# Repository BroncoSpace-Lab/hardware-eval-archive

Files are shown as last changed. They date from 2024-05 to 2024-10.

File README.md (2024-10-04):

# hardware-eval-archive

This is a new repo for us to store archived hardware evaluations! 

## Archiving a New Eval
To add your recently completed eval to this repo take the following steps: 
1. Make a new branch!
2. Add your files into a new folder with your name and the date in yyyy-mm-dd format. 
3. Make a pull reqest back to the main branch!

## Hardware Eval Instructions Reference: 
Since you're interested in leaning more towards the electronics side of things, we have an evaluation that we usually give prospective hardware engineers in our lab 1 week to complete if you would like to attempt it. For that evaluation, the task will be to create a custom microcontroller development board. The requirements are as follows:

- Design a PCB that uses an [RP2040 microcontroller](https://www.raspberrypi.com/documentation/microcontrollers/rp2040.html)
- Needs to be able to boot CircuitPython.
- Board Form Factor of no greater than 50x50mm
- Has an I2C sensor integrated (any sensor).
- JLC PCB production files completed (BOM, POS, and Gerbers generated in correct format)
- Preferably designed in KiCad (Eagle or Altium will also suffice)

We understand that PCB design is not usually taught at the university level, so it is rare to have prior experience with it. This challenge is primarily to test your ability to be technically independent and learn a new design skill quickly. Both [Digikey](https://www.youtube.com/@digikey) and [Phil's Lab](https://www.youtube.com/@PhilsLab) on YouTube have excellent beginner level PCB design tutorials. If you have the time to attempt it over the weekend that would be great, but don't worry if you need more time. A follow-up design review can be scheduled to assess how you have done, and if the design looks satisfactory, we'll go ahead and order it for you to test!

__Bonus Criteria__
- Make your board as compact as possible
- Ensure that either all of the GPIO are broken out and/or have some kind of connector system (like STEMMA QT) for wiring up additional peripherals
- Make the board look cool by adding silkscreen or soldermask art!

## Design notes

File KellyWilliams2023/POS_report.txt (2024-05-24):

Info: Front (top side) placement file: 'D:\Users\2790755\Documents\KiCad\SCALES PCB\minimal viable board design files\Minimal\RP2040_minimal\RP2040_minimal-top.pos'.
Info: Component count: 35.
Info: Back (bottom side) placement file: 'D:\Users\2790755\Documents\KiCad\SCALES PCB\minimal viable board design files\Minimal\RP2040_minimal\RP2040_minimal-bottom.pos'.
Info: Component count: 0.
Info: Full component count: 35.
Info: File generation successful.

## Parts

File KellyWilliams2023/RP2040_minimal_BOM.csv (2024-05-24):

Id | Designator | Footprint | Quantity | Designation | Supplier and ref
1 | C4,C1,C17 | C_0805_2012Metric | 3 | 10u
2 | J1 | USB_Micro-B_Amphenol_10103594-0001LF_Horizontal_modified | 1 | USB_B_Micro
3 | J2 | PinHeader_1x02_P2.54mm_Vertical | 1 | Conn_01x02
4 | J3,J4 | PinHeader_2x18_P2.54mm_Vertical | 2 | Conn_02x18_Odd_Even
5 | C10,C8 | C_0402_1005Metric | 2 | 1u
6 | C13,C5,C9,C12,C14,C7,C11,C16,C6,C15,C19,C18 | C_0402_1005Metric | 12 | 100n
7 | R2 | C_0402_1005Metric | 1 | DNF
8 | U1 | SOT-223-3_TabPin2 | 1 | NCP1117-3.3_SOT223
9 | U2 | SOIC-8_5.23x5.23mm_P1.27mm | 1 | W25Q128JVS
10 | C3,C2 | C_0402_1005Metric | 2 | 27p
11 | R1,R5 | C_0402_1005Metric | 2 | 1k
12 | R3,R4 | C_0402_1005Metric | 2 | 27
13 | U3 | RP2040-QFN-56 | 1 | RP2040
14 | H2,H3,H1,H4 | MountingHole_2.7mm_M2.5 | 4 | MountingHole
15 | Y1 | Crystal_SMD_HC49-US | 1 | ABLS-12.000MHZ-B4-T
16 | R6,R7 | C_0402_1005Metric | 2 | 4.7k
17 | U4 | Bosch_LGA-8_2.5x2.5mm_P0.65mm_ClockwisePinNumbering | 1 | BME280

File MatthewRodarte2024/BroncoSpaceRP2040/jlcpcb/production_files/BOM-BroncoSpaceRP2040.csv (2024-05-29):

Comment | Designator | Footprint | LCSC
10u | C1,C16,C2 | C_0805_2012Metric | C1046
1k | R4,R5 | R_0402_1005Metric | C11702
2N3906 | Q1 | TO-92_Inline | C124483
100n | C10,C11,C12,C13,C18,C4,C5,C7,C8,C9 | C_0402_1005Metric | C1525
100p | C17 | C_0402_1005Metric | C1546
27R4 | R1,R2 | R_0402_1005Metric | C172043
15p | C14,C15 | C_0402_1005Metric | C17944
RP2040 | U1 | QFN-56-1EP_7x7mm_P0.4mm_EP3.2x3.2mm | C2040
ABM8-272-T3 | Y1 | Crystal_SMD_3225-4Pin_3.2x2.5mm | C20625731
470 | R_Limit1 | R_0603_1608Metric | C23179
10k | R10,R7,R8 | R_0402_1005Metric | C25744
NCP1117-3.3_SOT223 | U2 | SOT-223-3_TabPin2 | C26537
USB_B_Micro | J1 | USB_Micro-B_Amphenol_10103594-0001LF_Horizontal | C2681556
TMP461xxRUN | U4 | Texas_WQFN-10_2x2mm_P0.5mm | C2873234
1u | C3,C6 | C_0402_1005Metric | C52923
W25Q128JVS | U3 | SOIC-8_5.23x5.23mm_P1.27mm | C97521
MountingHole | H3 | MountingHole_2.7mm_M2.5
Conn_01x18 | J4 | PinHeader_1x18_P2.54mm_Vertical
MountingHole | H2 | MountingHole_2.7mm_M2.5
Conn_01x02 | J2 | PinHeader_1x02_P2.54mm_Vertical
MountingHole | H1 | MountingHole_2.7mm_M2.5
MountingHole | H4 | MountingHole_2.7mm_M2.5
Conn_01x18 | J3 | PinHeader_1x18_P2.54mm_Vertical
LED | D1 | LED_D3.0mm
DNF | R3 | R_0402_1005Metric

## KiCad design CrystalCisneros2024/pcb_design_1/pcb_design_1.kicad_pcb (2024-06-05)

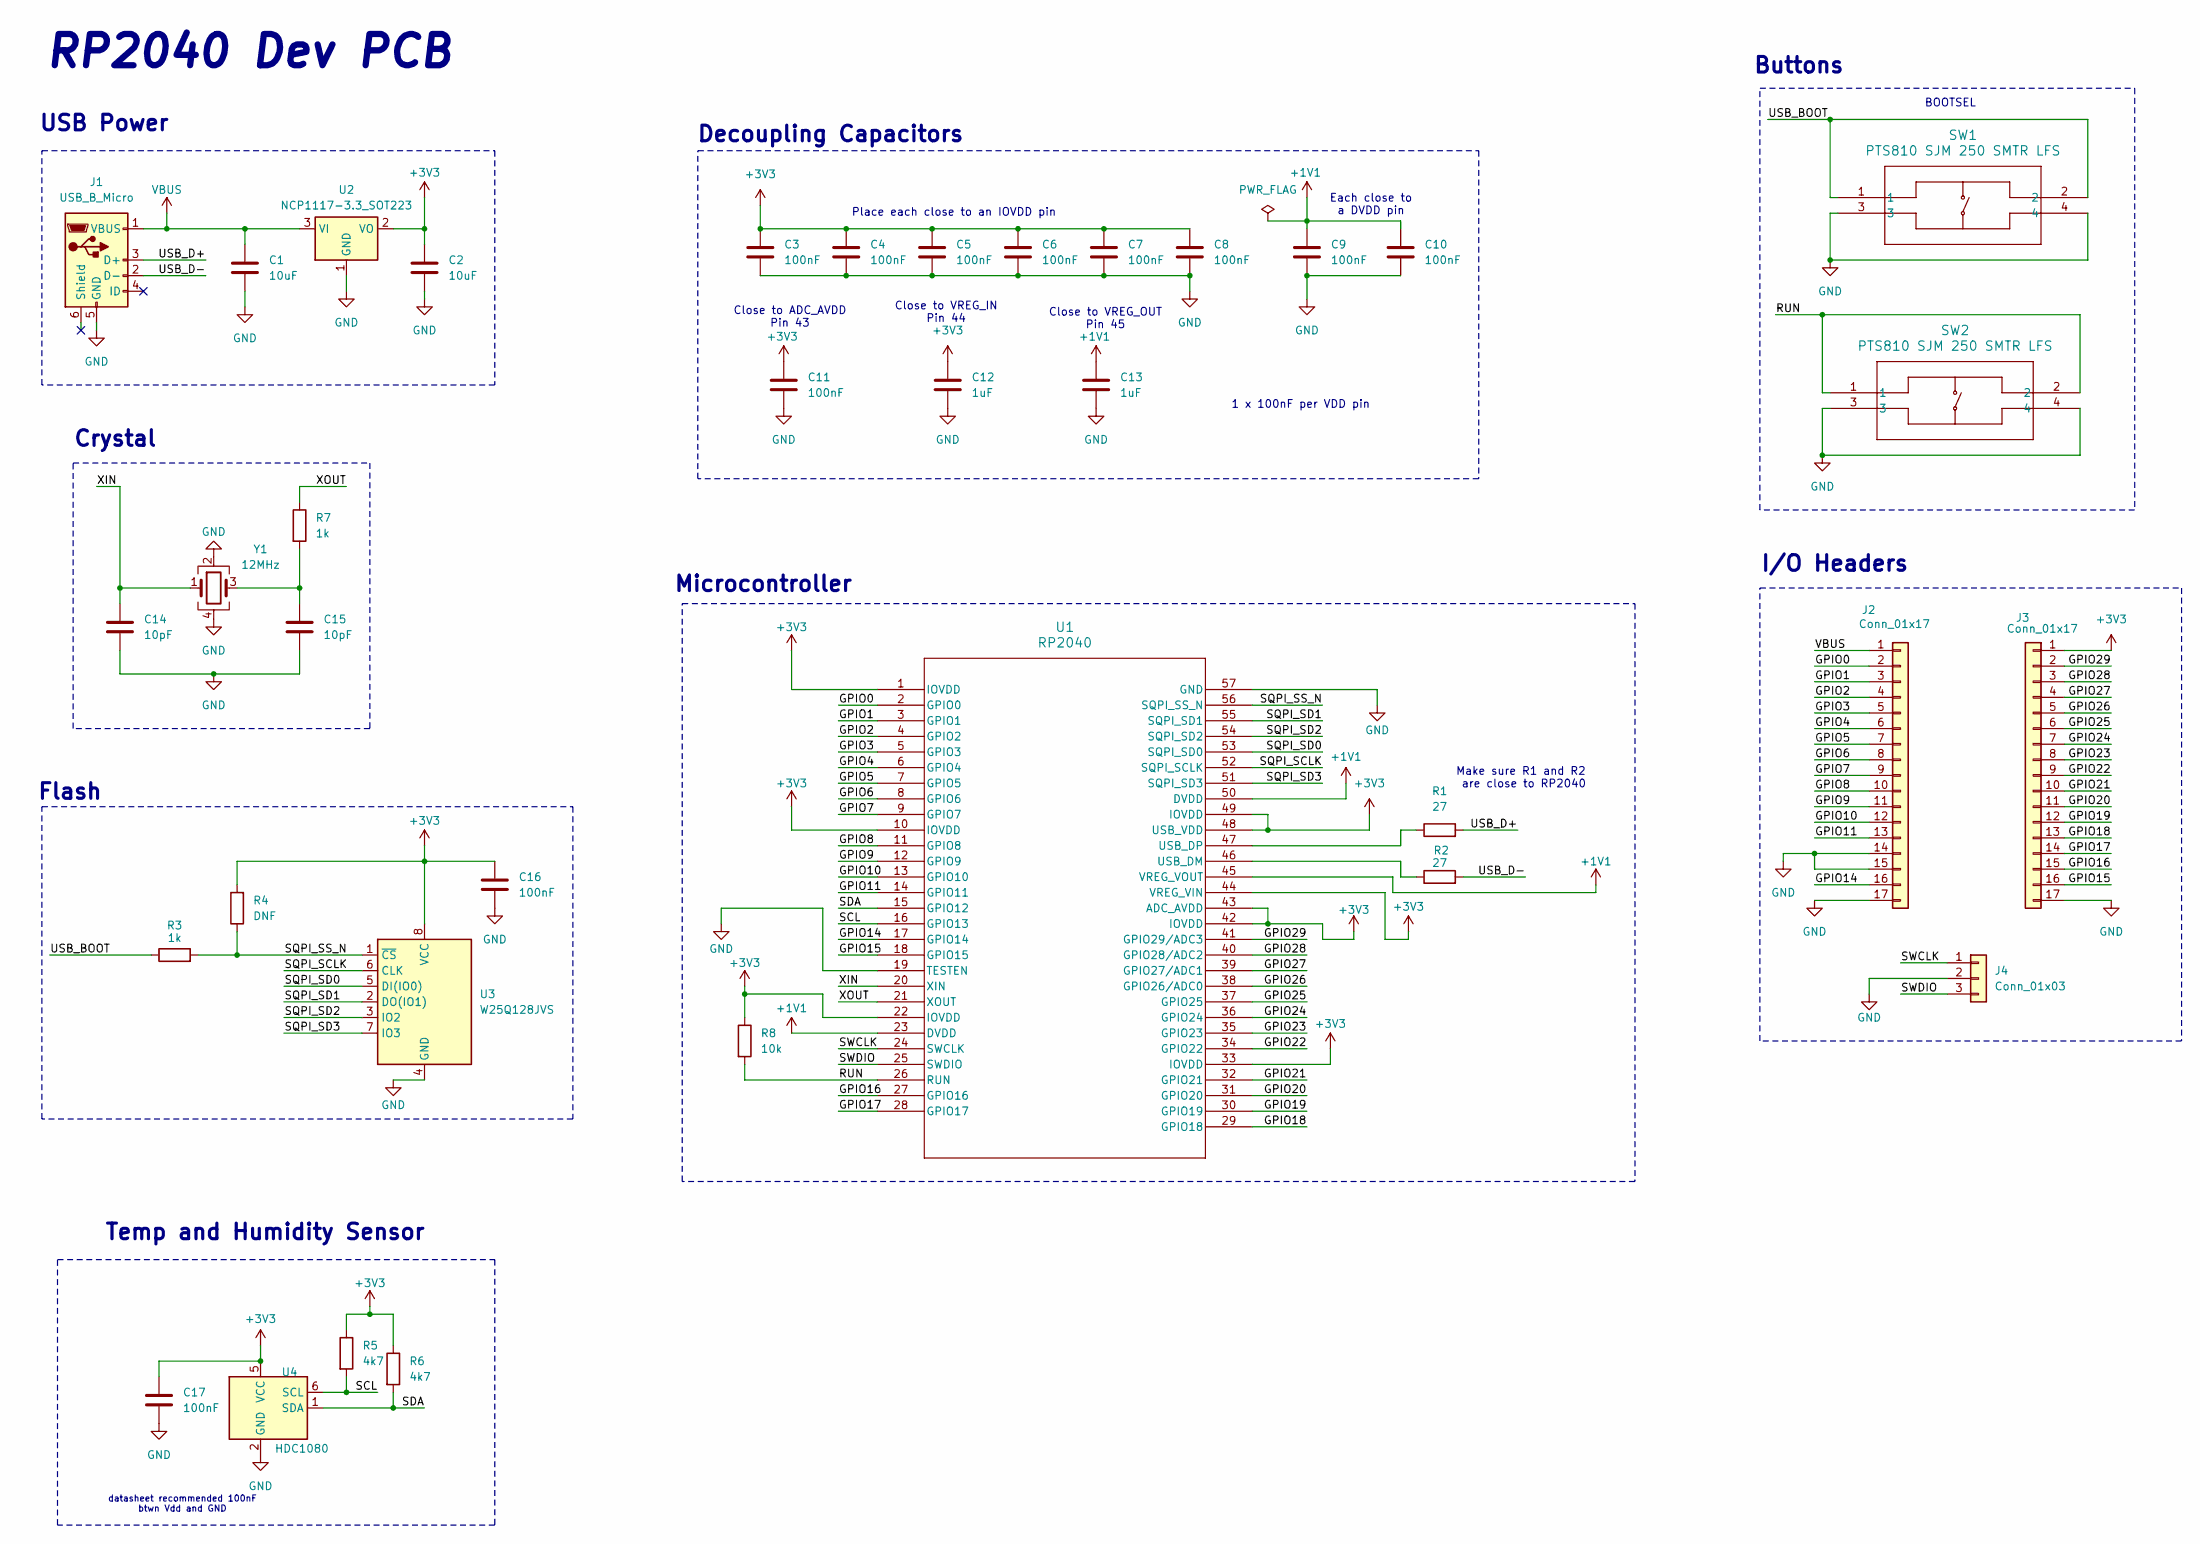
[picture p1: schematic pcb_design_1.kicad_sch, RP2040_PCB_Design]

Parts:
C1, C2: 10uF; C_0603_1608Metric
C3, C4, C5, C6, C7, C8, C9, C10, C11, C16, C17: 100nF; C_0402_1005Metric
C12, C13: 1uF; C_0603_1608Metric
C14, C15: 10pF; C_0402_1005Metric
J1: USB_B_Micro; USB_Micro-B_Wuerth_629105150521
J2, J3: Conn_01x17; PinHeader_1x17_P2.54mm_Vertical
J4: Conn_01x03; PinHeader_1x03_P2.54mm_Vertical
R1, R2: 27; R_0402_1005Metric
R3, R7: 1k; R_0402_1005Metric
R4: DNF; R_0402_1005Metric
R5, R6: 4k7; R_0402_1005Metric
R8: 10k; R_0402_1005Metric
SW1, SW2: PTS810 SJM 250 SMTR LFS; PTS810_CNK
U1: RP2040; QFN-56-1EP_7x7mm_P0.4mm_EP3.2x3.2mm
U2: NCP1117-3.3_SOT223; SOT-223-3_TabPin2
U3: W25Q128JVS; SOIC-8_5.23x5.23mm_P1.27mm
U4: HDC1080; Texas_PWSON-N6
Y1: 12MHz; Crystal_SMD_2520-4Pin_2.5x2.0mm

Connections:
+1V1: C9.1, C10.1, C13.1, U1.23 (DVDD), U1.45 (VREG_VOUT), U1.50 (DVDD)
+3V3: C2.1, C3.1, C4.1, C5.1, C6.1, C7.1, C8.1, C11.1, C12.1, C16.1, C17.1, J3.1, R4.2, R5.1, R6.1, R8.1, U1.1 (IOVDD), U1.10 (IOVDD), U1.22 (IOVDD), U1.33 (IOVDD), U1.42 (IOVDD), U1.43 (ADC_AVDD), U1.44 (VREG_VIN), U1.48 (USB_VDD), U1.49 (IOVDD), U2.2 (VO), U3.8 (VCC), U4.5 (VCC)
/GPIO0: J2.2, U1.2 (GPIO0)
/GPIO1: J2.3, U1.3 (GPIO1)
/GPIO2: J2.4, U1.4 (GPIO2)
/GPIO3: J2.5, U1.5 (GPIO3)
/GPIO4: J2.6, U1.6 (GPIO4)
/GPIO5: J2.7, U1.7 (GPIO5)
/GPIO6: J2.8, U1.8 (GPIO6)
/GPIO7: J2.9, U1.9 (GPIO7)
/GPIO8: J2.10, U1.11 (GPIO8)
/GPIO9: J2.11, U1.12 (GPIO9)
/GPIO10: J2.12, U1.13 (GPIO10)
/GPIO11: J2.13, U1.14 (GPIO11)
/GPIO14: J2.16, U1.17 (GPIO14)
/GPIO15: J3.16, U1.18 (GPIO15)
/GPIO16: J3.15, U1.27 (GPIO16)
/GPIO17: J3.14, U1.28 (GPIO17)
/GPIO18: J3.13, U1.29 (GPIO18)
/GPIO19: J3.12, U1.30 (GPIO19)
/GPIO20: J3.11, U1.31 (GPIO20)
/GPIO21: J3.10, U1.32 (GPIO21)
/GPIO22: J3.9, U1.34 (GPIO22)
/GPIO23: J3.8, U1.35 (GPIO23)
/GPIO24: J3.7, U1.36 (GPIO24)
/GPIO25: J3.6, U1.37 (GPIO25)
/GPIO26: J3.5, U1.38 (GPIO26/ADC0)
/GPIO27: J3.4, U1.39 (GPIO27/ADC1)
/GPIO28: J3.3, U1.40 (GPIO28/ADC2)
/GPIO29: J3.2, U1.41 (GPIO29/ADC3)
/RUN: R8.2, SW2.1, SW2.2, U1.26 (RUN)
/SCL: R5.2, U1.16 (GPIO13), U4.6 (SCL)
/SDA: R6.2, U1.15 (GPIO12), U4.1 (SDA)
/SQPI_SCLK: U1.52 (SQPI_SCLK), U3.6 (CLK)
/SQPI_SD0: U1.53 (SQPI_SD0), U3.5 (DI(IO0))
/SQPI_SD1: U1.55 (SQPI_SD1), U3.2 (DO(IO1))
/SQPI_SD2: U1.54 (SQPI_SD2), U3.3 (IO2)
/SQPI_SD3: U1.51 (SQPI_SD3), U3.7 (IO3)
/SQPI_SS_N: R3.2, R4.1, U1.56 (SQPI_SS_N), U3.1 (~CS)
/SWCLK: J4.1, U1.24 (SWCLK)
/SWDIO: J4.3, U1.25 (SWDIO)
/USB_BOOT: R3.1, SW1.1, SW1.2
/USB_D+: J1.3 (D+), R1.2
/USB_D-: J1.2 (D-), R2.2
/XIN: C14.1, U1.20 (XIN), Y1.1
/XOUT: R7.1, U1.21 (XOUT)
GND: C1.2, C2.2, C3.2, C4.2, C5.2, C6.2, C7.2, C8.2, C9.2, C10.2, C11.2, C12.2, C13.2, C14.2, C15.2, C16.2, C17.2, J1.5 (GND), J2.14, J2.15, J2.17, J3.17, J4.2, SW1.3, SW1.4, SW2.3, SW2.4, U1.19 (TESTEN), U1.57 (GND), U2.1 (GND), U3.4 (GND), U4.2 (GND), Y1.2, Y1.4
unnamed: C15.1, R7.2, Y1.3
unnamed: R2.1, U1.46 (USB_DM)
unnamed: R1.1, U1.47 (USB_DP)
VBUS: C1.1, J1.1 (VBUS), J2.1, U2.3 (VI)

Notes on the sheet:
1 x 100nF per VDD pin
Microcontroller
Flash
Make sure R1 and R2 are close to RP2040
Crystal
Close to VREG_OUT Pin 45
I/O Headers
Decoupling Capacitors
Close to ADC_AVDD Pin 43
BOOTSEL
Place each close to an IOVDD pin
Close to VREG_IN Pin 44
RP2040 Dev PCB
Each close to a DVDD pin
Buttons
datasheet recommended 100nF btwn Vdd and GND
Temp and Humidity Sensor
USB Power

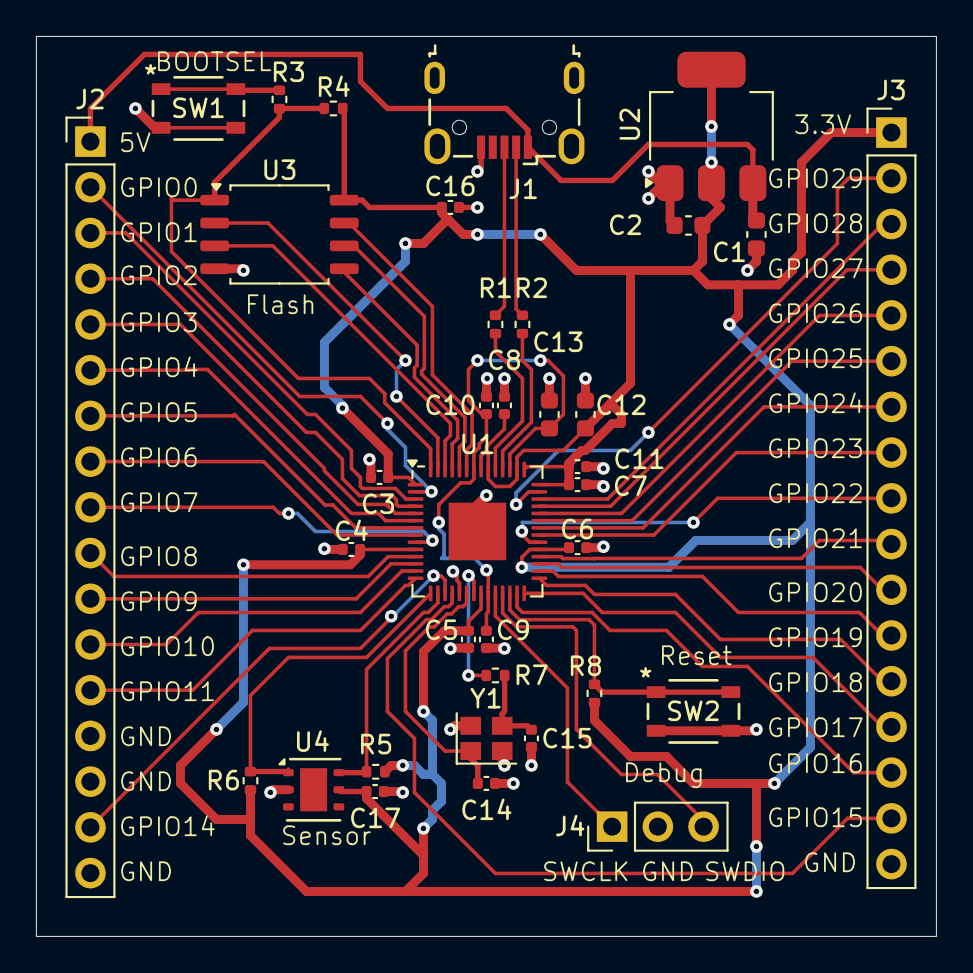
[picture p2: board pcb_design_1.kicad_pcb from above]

Board: 2 copper layers, 50.0 x 50.0 mm, 36 parts (0 on the bottom side), 51 nets.

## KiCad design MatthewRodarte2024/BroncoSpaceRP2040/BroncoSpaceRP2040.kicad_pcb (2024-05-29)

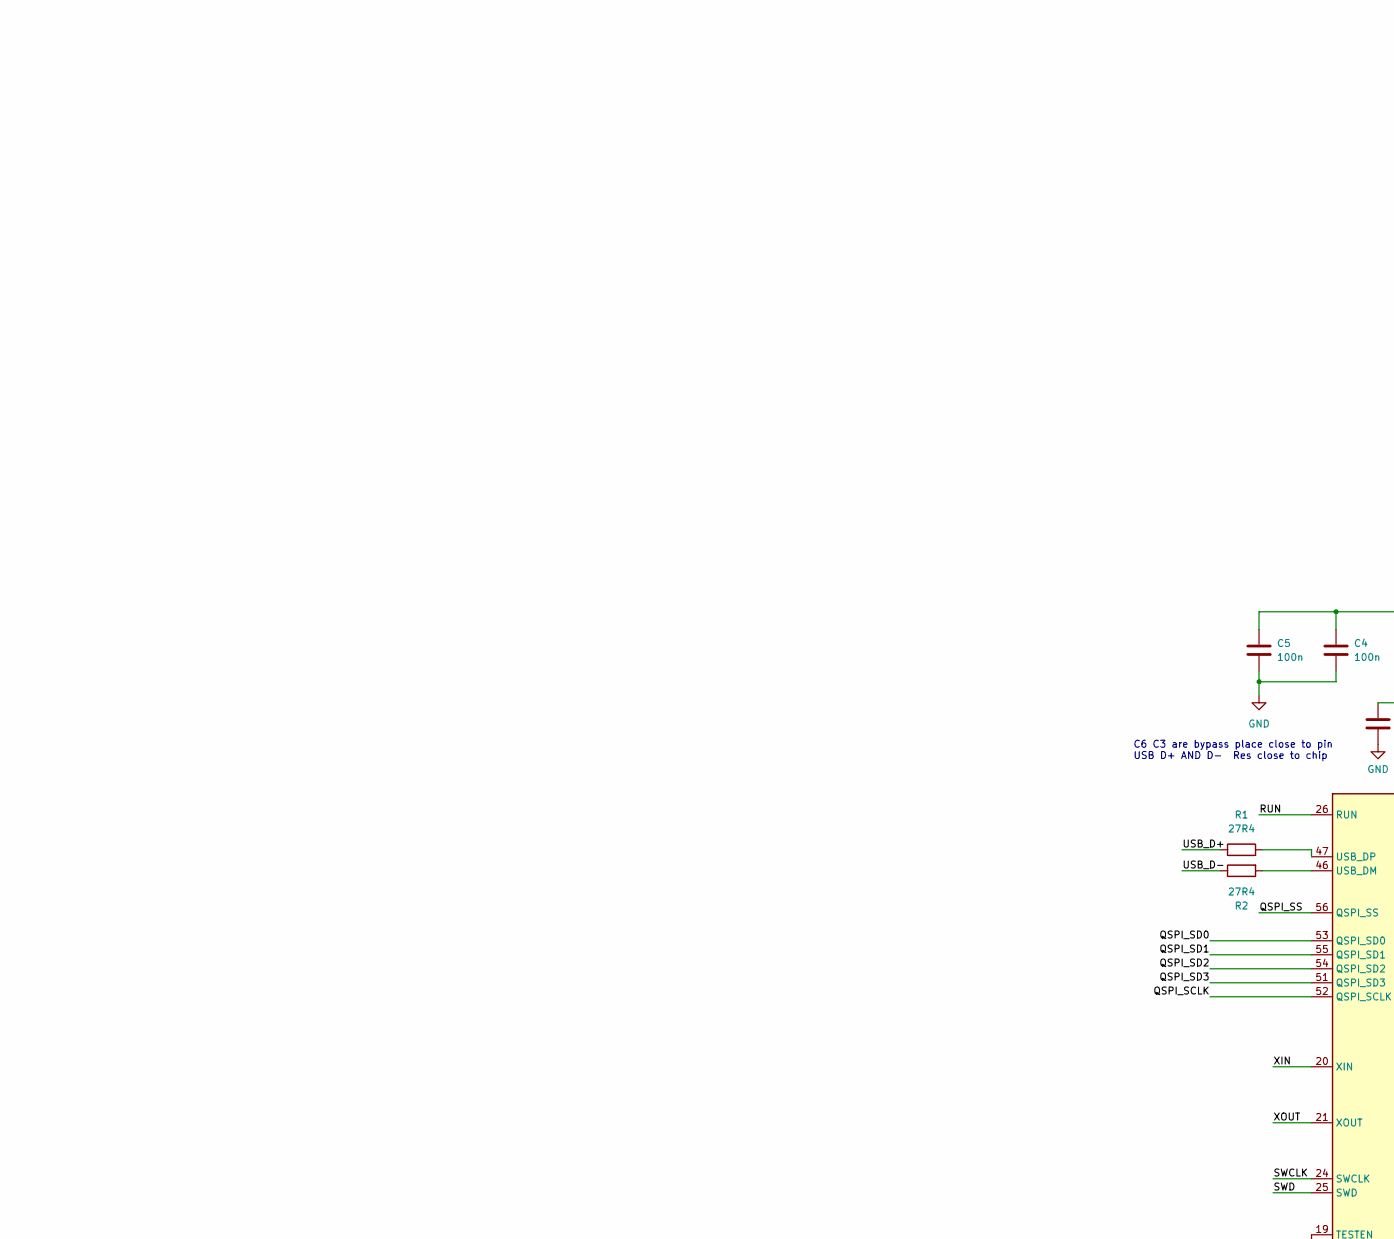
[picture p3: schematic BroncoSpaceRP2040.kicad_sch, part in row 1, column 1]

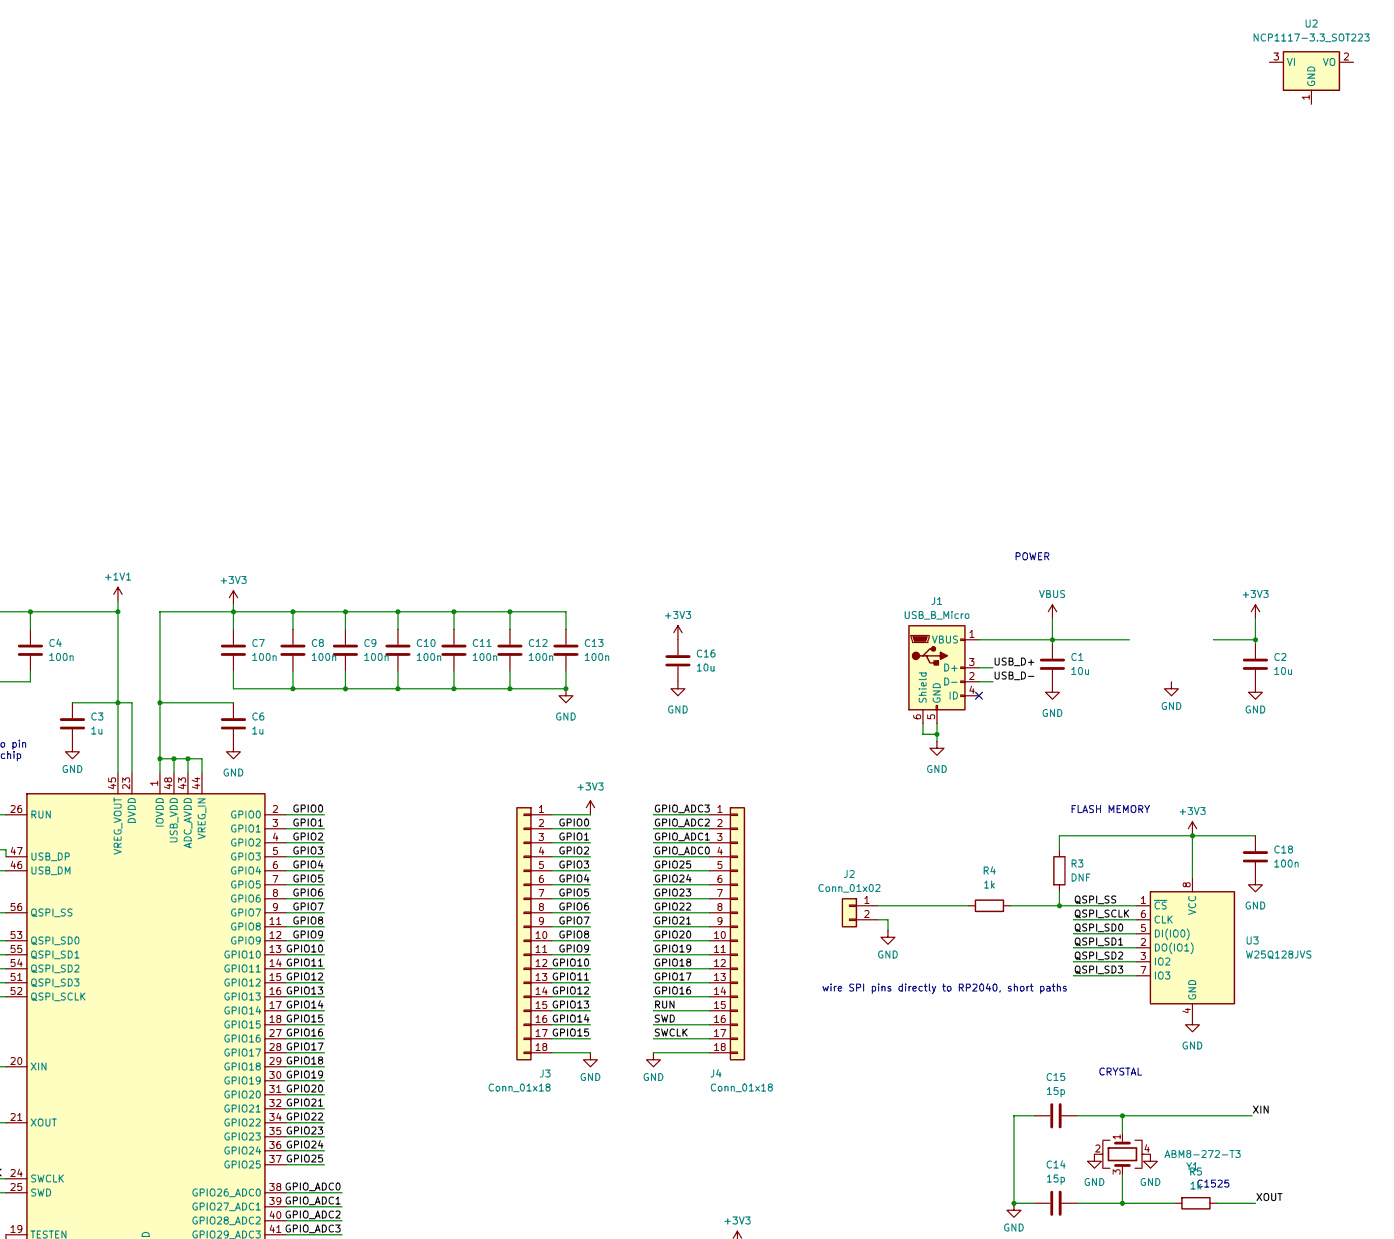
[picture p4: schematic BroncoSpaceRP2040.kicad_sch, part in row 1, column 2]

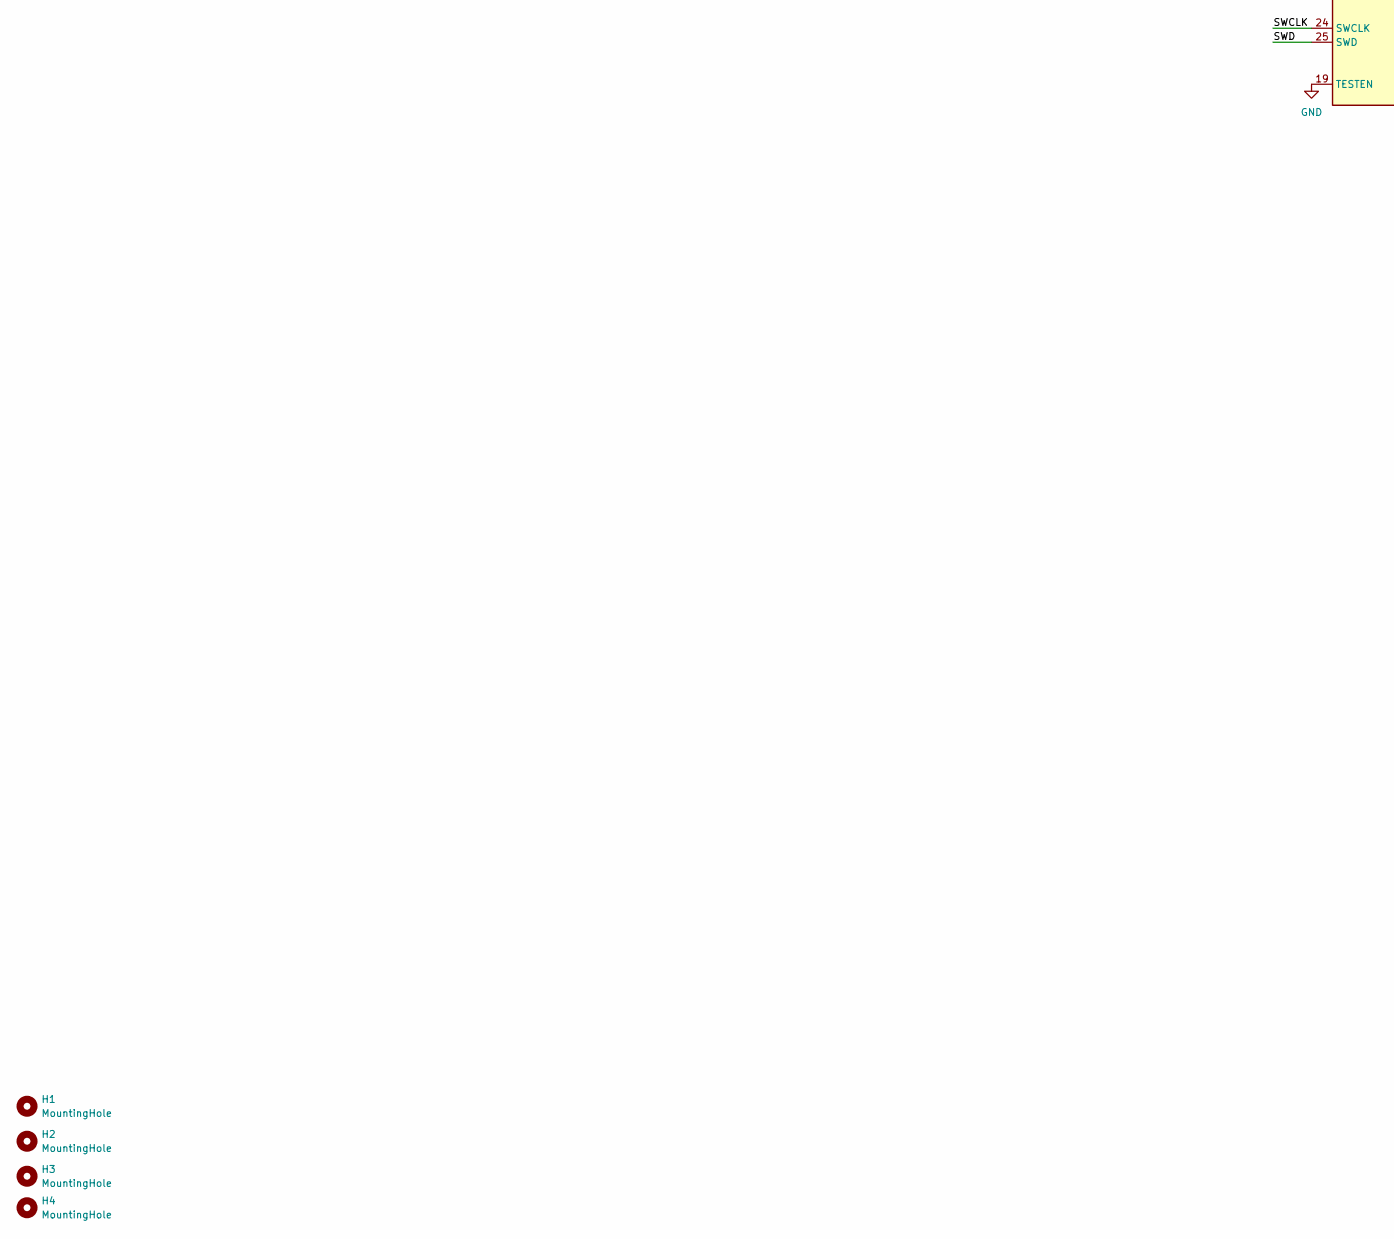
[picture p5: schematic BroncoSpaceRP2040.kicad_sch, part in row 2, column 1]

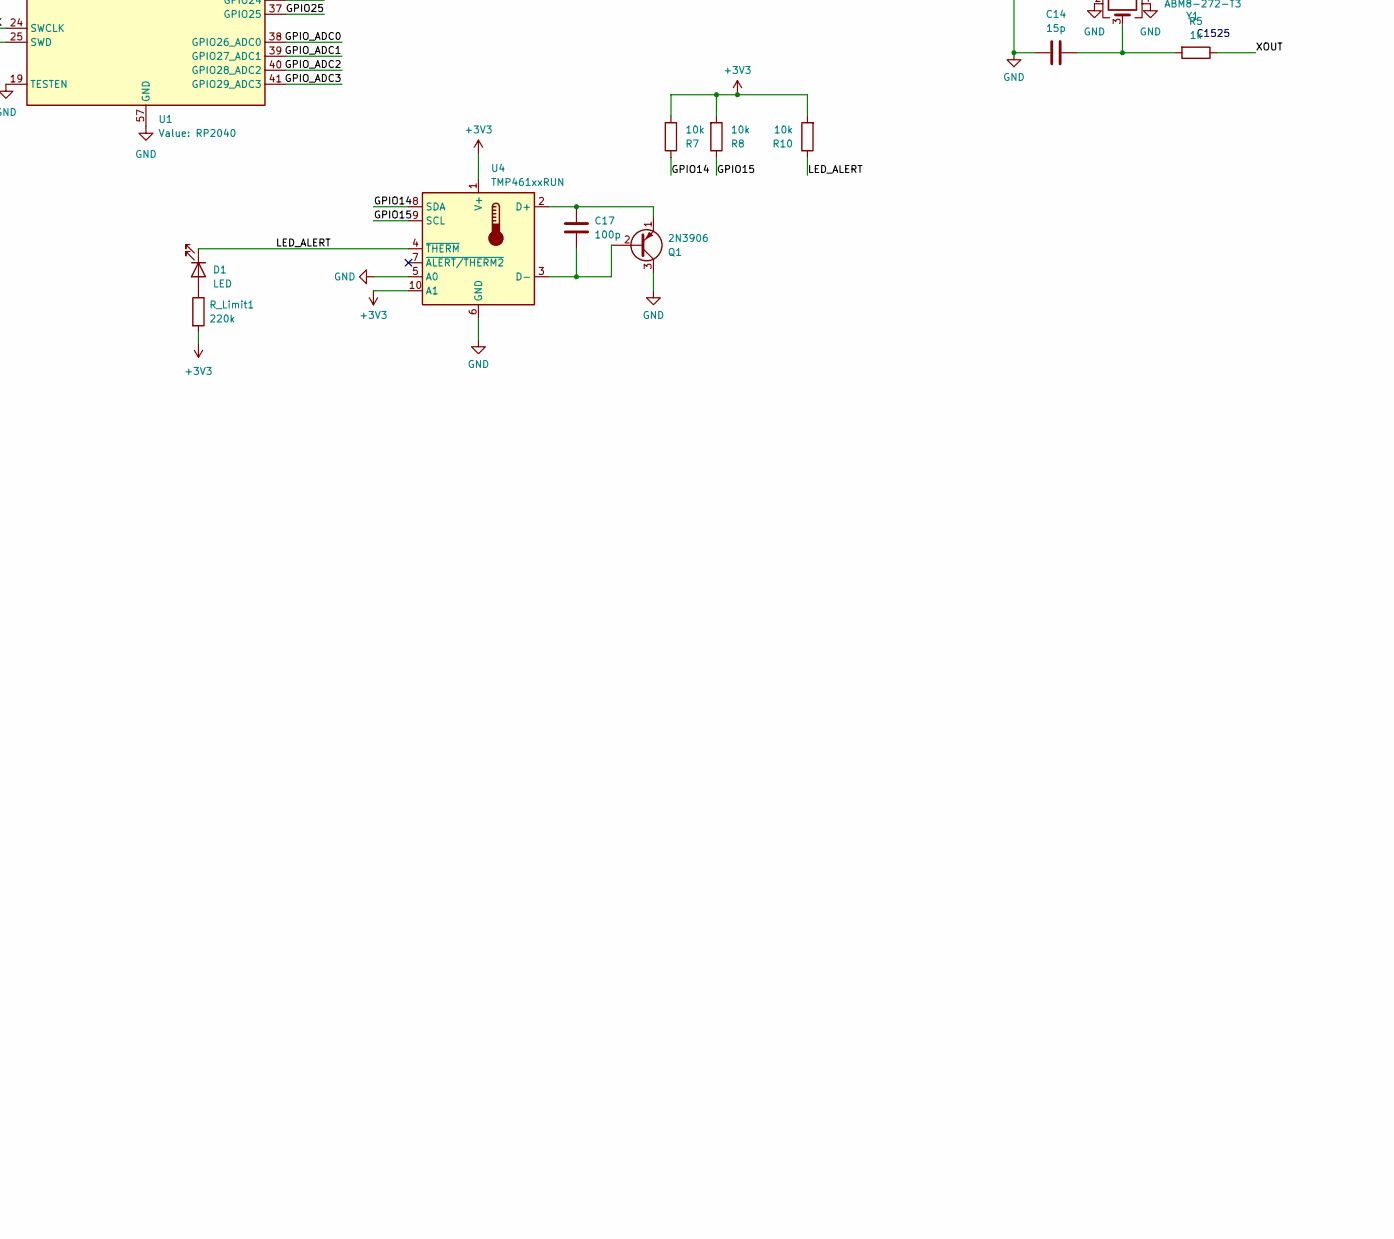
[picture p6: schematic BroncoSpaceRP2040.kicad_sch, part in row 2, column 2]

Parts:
C1, C2: 10u; C_0805_2012Metric; LCSC C1046
C3, C6: 1u; C_0402_1005Metric; LCSC C29266
C4, C5, C7, C8, C9, C10, C11, C12, C13, C18: 100n; C_0402_1005Metric; LCSC C1525
C14, C15: 15p; C_0402_1005Metric; LCSC C1794
C16: 10u; C_0402_1005Metric; LCSC C1046
C17: 100p; C_0402_1005Metric; LCSC C26409
D1: LED; LED_D3.0mm; LCSC C10679
H1, H2, H3, H4: MountingHole; MountingHole_2.7mm_M2.5
J1: USB_B_Micro; USB_Micro-B_Amphenol_10103594-0001LF_Horizontal; LCSC C2681556
J2: Conn_01x02; PinHeader_1x02_P2.54mm_Vertical; LCSC C2905434
J3, J4: Conn_01x18; PinHeader_1x18_P2.54mm_Vertical; LCSC C5142873
Q1: 2N3906; TO-92_Inline; LCSC C124483
R1, R2: 27R4; R_0402_1005Metric; LCSC C172043
R3: DNF; R_0402_1005Metric
R4, R5: 1k; R_0402_1005Metric; LCSC C1525
R7, R8, R10: 10k; R_0402_1005Metric; LCSC C1525
R_Limit1: 220k; R_0805_2012Metric
U1: RP2040; QFN-56-1EP_7x7mm_P0.4mm_EP3.2x3.2mm; LCSC C2040
U2: NCP1117-3.3_SOT223; SOT-223-3_TabPin2; LCSC C26537
U3: W25Q128JVS; SOIC-8_5.23x5.23mm_P1.27mm; LCSC C97521
U4: TMP461xxRUN; Texas_WQFN-10_2x2mm_P0.5mm; LCSC C2873234
Y1: ABM8-272-T3; Crystal_SMD_3225-4Pin_3.2x2.5mm; LCSC C20625731

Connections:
+1V1: C3.1, C4.1, C5.1, U1.23 (DVDD), U1.45 (VREG_VOUT), U1.50 (DVDD)
+3V3: C2.1, C6.1, C7.1, C8.1, C9.1, C10.1, C11.1, C12.1, C13.1, C16.1, C18.1, J3.1, R3.1, R7.2, R8.2, R10.2, R_Limit1.2, U1.1 (IOVDD), U1.10 (IOVDD), U1.22 (IOVDD), U1.33 (IOVDD), U1.42 (IOVDD), U1.43 (ADC_AVDD), U1.44 (VREG_IN), U1.48 (USB_VDD), U1.49 (IOVDD), U2.2 (VO), U3.8 (VCC), U4.1 (V+), U4.10 (A1)
/GPIO0: J3.2, U1.2 (GPIO0)
/GPIO1: J3.3, U1.3 (GPIO1)
/GPIO2: J3.4, U1.4 (GPIO2)
/GPIO3: J3.5, U1.5 (GPIO3)
/GPIO4: J3.6, U1.6 (GPIO4)
/GPIO5: J3.7, U1.7 (GPIO5)
/GPIO6: J3.8, U1.8 (GPIO6)
/GPIO7: J3.9, U1.9 (GPIO7)
/GPIO8: J3.10, U1.11 (GPIO8)
/GPIO9: J3.11, U1.12 (GPIO9)
/GPIO10: J3.12, U1.13 (GPIO10)
/GPIO11: J3.13, U1.14 (GPIO11)
/GPIO12: J3.14, U1.15 (GPIO12)
/GPIO13: J3.15, U1.16 (GPIO13)
/GPIO14: J3.16, R7.1, U1.17 (GPIO14), U4.8 (SDA)
/GPIO15: J3.17, R8.1, U1.18 (GPIO15), U4.9 (SCL)
/GPIO16: J4.14, U1.27 (GPIO16)
/GPIO17: J4.13, U1.28 (GPIO17)
/GPIO18: J4.12, U1.29 (GPIO18)
/GPIO19: J4.11, U1.30 (GPIO19)
/GPIO20: J4.10, U1.31 (GPIO20)
/GPIO21: J4.9, U1.32 (GPIO21)
/GPIO22: J4.8, U1.34 (GPIO22)
/GPIO23: J4.7, U1.35 (GPIO23)
/GPIO24: J4.6, U1.36 (GPIO24)
/GPIO25: J4.5, U1.37 (GPIO25)
/GPIO_ADC0: J4.4, U1.38 (GPIO26_ADC0)
/GPIO_ADC1: J4.3, U1.39 (GPIO27_ADC1)
/GPIO_ADC2: J4.2, U1.40 (GPIO28_ADC2)
/GPIO_ADC3: J4.1, U1.41 (GPIO29_ADC3)
/LED_ALERT: D1.1 (K), R10.1, U4.4 (~THERM)
/QSPI_SCLK: U1.52 (QSPI_SCLK), U3.6 (CLK)
/QSPI_SD0: U1.53 (QSPI_SD0), U3.5 (DI(IO0))
/QSPI_SD1: U1.55 (QSPI_SD1), U3.2 (DO(IO1))
/QSPI_SD2: U1.54 (QSPI_SD2), U3.3 (IO2)
/QSPI_SD3: U1.51 (QSPI_SD3), U3.7 (IO3)
/QSPI_SS: R3.2, R4.2, U1.56 (QSPI_SS), U3.1 (~CS)
/RUN: J4.15, U1.26 (RUN)
/SWCLK: J4.17, U1.24 (SWCLK)
/SWD: J4.16, U1.25 (SWD)
/USB_D+: J1.3 (D+), R1.1
/USB_D-: J1.2 (D-), R2.1
/XIN: C15.1, U1.20 (XIN), Y1.1
/XOUT: R5.1, U1.21 (XOUT)
GND: C1.2, C2.2, C3.2, C4.2, C5.2, C6.2, C7.2, C8.2, C9.2, C10.2, C11.2, C12.2, C13.2, C14.2, C15.2, C16.2, C18.2, J1.5 (GND), J1.6 (Shield), J2.2, J3.18, J4.18, Q1.3 (C), U1.19 (TESTEN), U1.57 (GND), U2.1 (GND), U3.4 (GND), U4.5 (A0), U4.6 (GND), Y1.2, Y1.4
unnamed: C14.1, R5.2, Y1.3
unnamed: D1.2 (A), R_Limit1.1
unnamed: J2.1, R4.1
unnamed: C17.2, Q1.2 (B), U4.3 (D-)
unnamed: C17.1, Q1.1 (E), U4.2 (D+)
unnamed: R2.2, U1.46 (USB_DM)
unnamed: R1.2, U1.47 (USB_DP)
VBUS: C1.1, J1.1 (VBUS), U2.3 (VI)

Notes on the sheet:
POWER
FLASH MEMORY
C1525
CRYSTAL
wire SPI pins directly to RP2040, short paths
C6 C3 are bypass place close to pin USB D+ AND D- Res close to chip

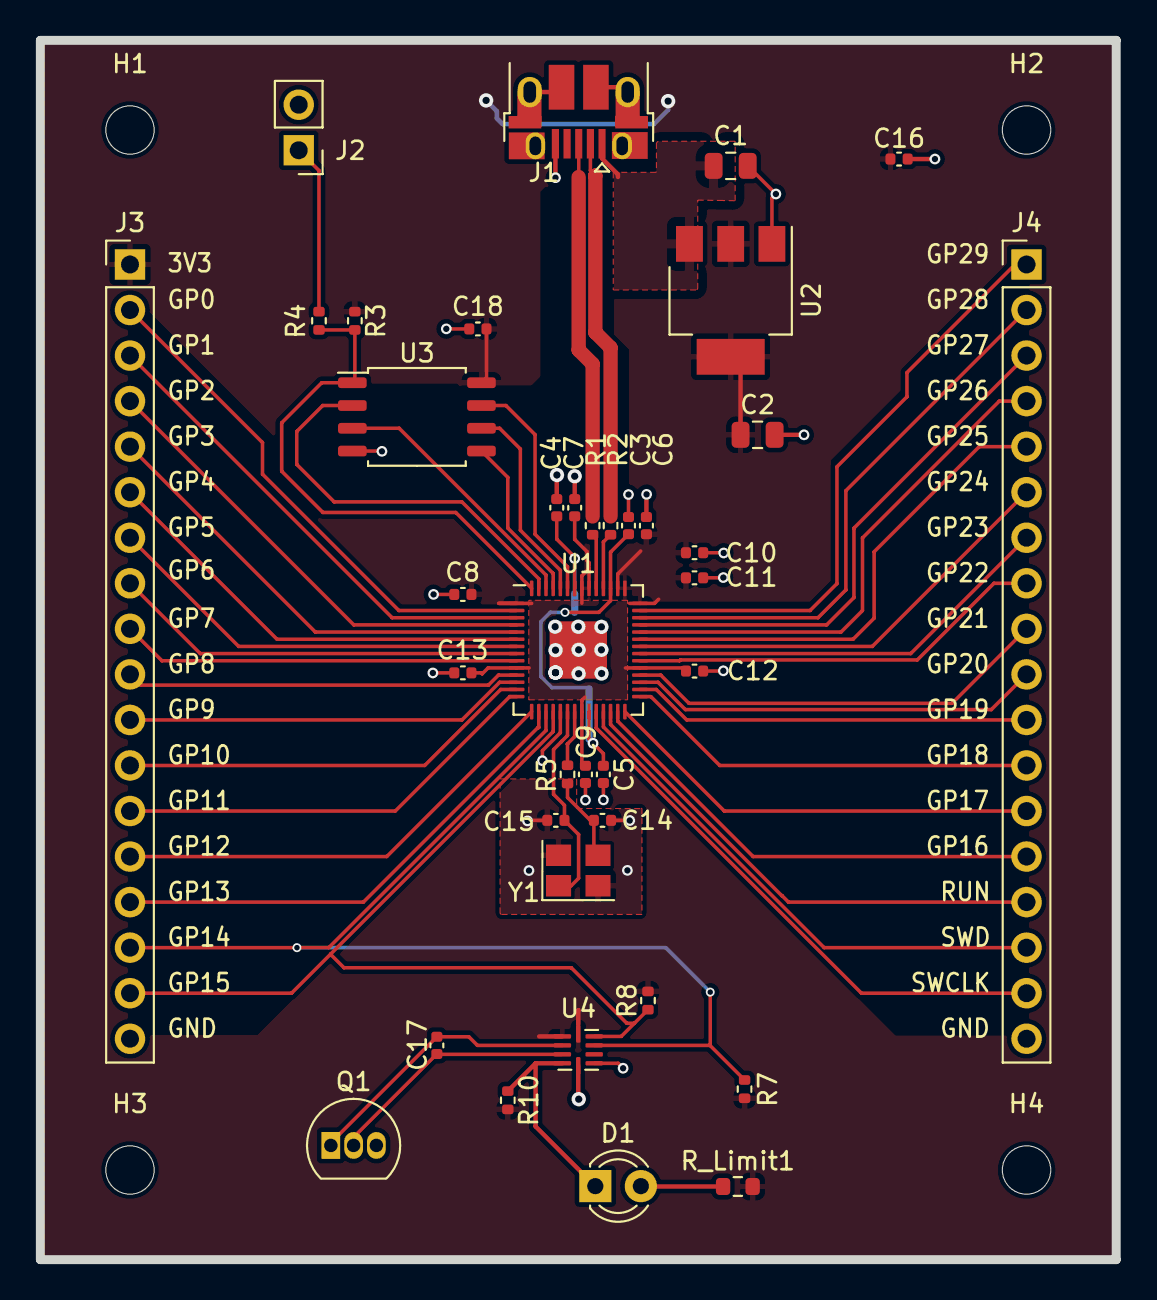
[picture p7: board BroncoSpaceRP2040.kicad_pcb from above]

Board: 2 copper layers, 60.0 x 68.0 mm, 42 parts (0 on the bottom side), 55 nets.

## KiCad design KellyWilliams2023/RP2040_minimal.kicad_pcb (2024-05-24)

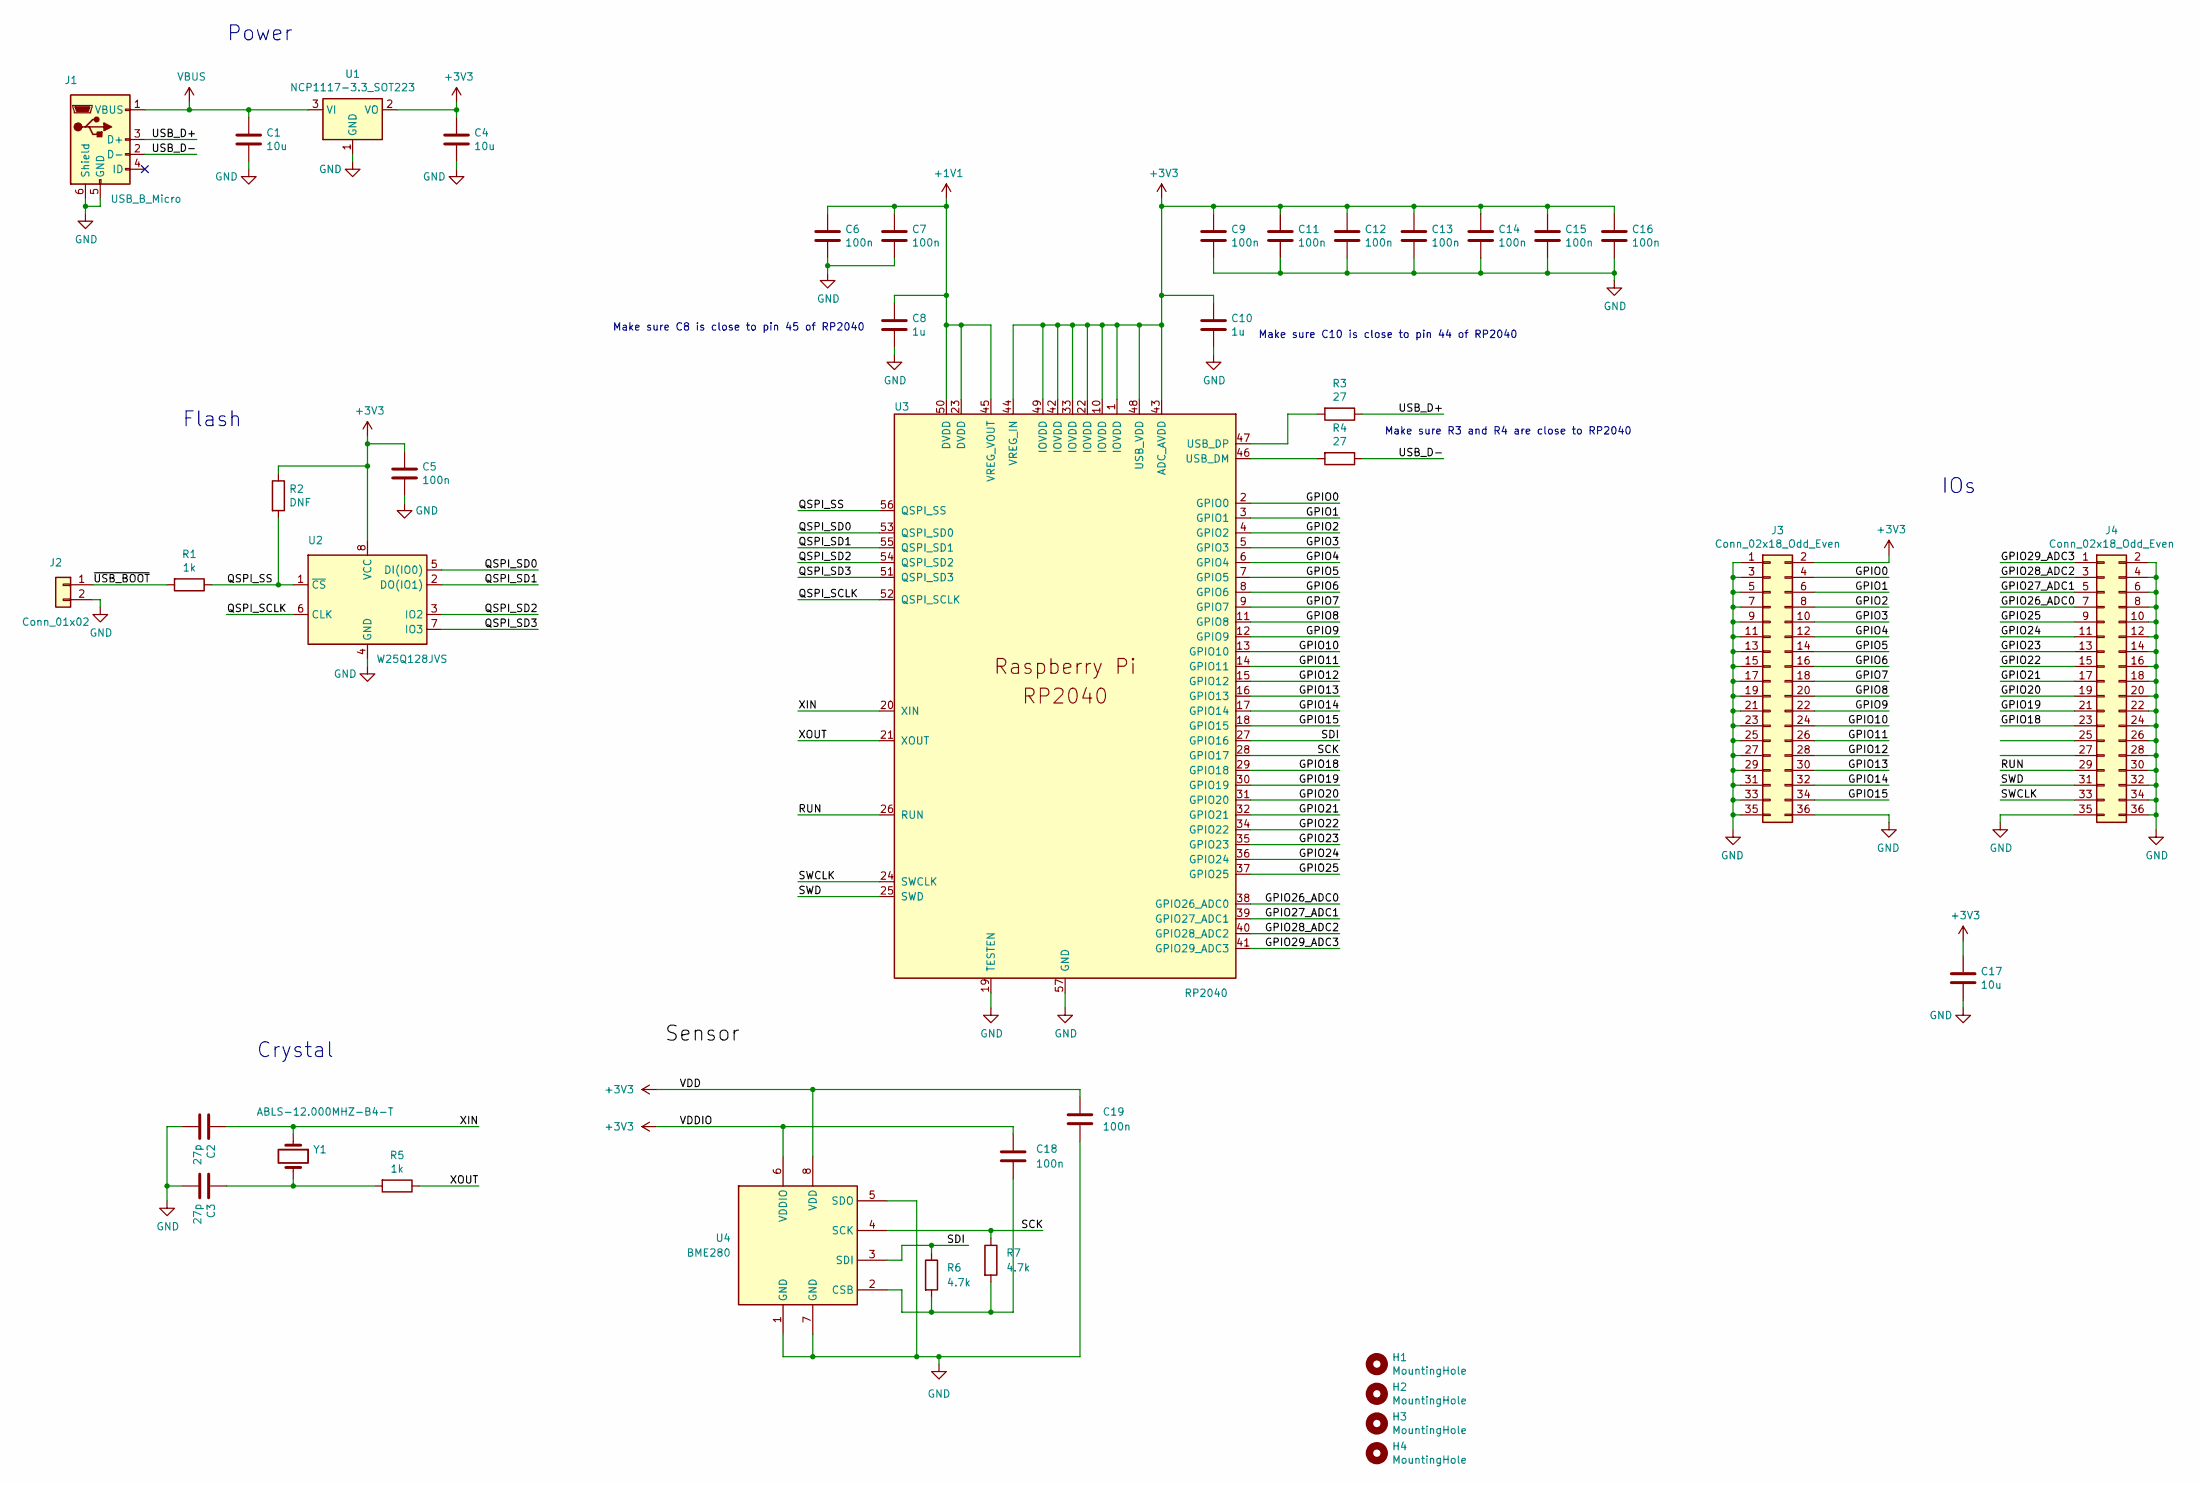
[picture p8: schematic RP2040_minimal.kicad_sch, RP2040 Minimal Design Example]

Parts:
C1, C4, C17: 10u; C_0805_2012Metric
C2, C3: 27p; C_0402_1005Metric
C5, C6, C7, C9, C11, C12, C13, C14, C15, C16, C18, C19: 100n; C_0402_1005Metric
C8, C10: 1u; C_0402_1005Metric
H1, H2, H3, H4: MountingHole; MountingHole_2.7mm_M2.5
J1: USB_B_Micro; USB_Micro-B_Amphenol_10103594-0001LF_Horizontal_modified
J2: Conn_01x02; PinHeader_1x02_P2.54mm_Vertical
J3, J4: Conn_02x18_Odd_Even; PinHeader_2x18_P2.54mm_Vertical
R1, R5: 1k; C_0402_1005Metric
R2: DNF; C_0402_1005Metric
R3, R4: 27; C_0402_1005Metric
R6, R7: 4.7k; C_0402_1005Metric
U1: NCP1117-3.3_SOT223; SOT-223-3_TabPin2
U2: W25Q128JVS; SOIC-8_5.23x5.23mm_P1.27mm
U3: RP2040; RP2040-QFN-56
U4: BME280; Bosch_LGA-8_2.5x2.5mm_P0.65mm_ClockwisePinNumbering
Y1: ABLS-12.000MHZ-B4-T; Crystal_SMD_HC49-US

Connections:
+1V1: C6.1, C7.1, C8.1, U3.23 (DVDD), U3.45 (VREG_VOUT), U3.50 (DVDD)
+3V3: C4.1, C5.1, C9.1, C10.1, C11.1, C12.1, C13.1, C14.1, C15.1, C16.1, C17.1, C18.1, C19.1, J3.2, R2.1, U1.2 (VO), U2.8 (VCC), U3.1 (IOVDD), U3.10 (IOVDD), U3.22 (IOVDD), U3.33 (IOVDD), U3.42 (IOVDD), U3.43 (ADC_AVDD), U3.44 (VREG_IN), U3.48 (USB_VDD), U3.49 (IOVDD), U4.6 (VDDIO), U4.8 (VDD)
/GPIO0: J3.4, U3.2 (GPIO0)
/GPIO1: J3.6, U3.3 (GPIO1)
/GPIO2: J3.8, U3.4 (GPIO2)
/GPIO3: J3.10, U3.5 (GPIO3)
/GPIO4: J3.12, U3.6 (GPIO4)
/GPIO5: J3.14, U3.7 (GPIO5)
/GPIO6: J3.16, U3.8 (GPIO6)
/GPIO7: J3.18, U3.9 (GPIO7)
/GPIO8: J3.20, U3.11 (GPIO8)
/GPIO9: J3.22, U3.12 (GPIO9)
/GPIO10: J3.24, U3.13 (GPIO10)
/GPIO11: J3.26, U3.14 (GPIO11)
/GPIO12: J3.28, U3.15 (GPIO12)
/GPIO13: J3.30, U3.16 (GPIO13)
/GPIO14: J3.32, U3.17 (GPIO14)
/GPIO15: J3.34, U3.18 (GPIO15)
/GPIO18: J4.23, U3.29 (GPIO18)
/GPIO19: J4.21, U3.30 (GPIO19)
/GPIO20: J4.19, U3.31 (GPIO20)
/GPIO21: J4.17, U3.32 (GPIO21)
/GPIO22: J4.15, U3.34 (GPIO22)
/GPIO23: J4.13, U3.35 (GPIO23)
/GPIO24: J4.11, U3.36 (GPIO24)
/GPIO25: J4.9, U3.37 (GPIO25)
/GPIO26_ADC0: J4.7, U3.38 (GPIO26_ADC0)
/GPIO27_ADC1: J4.5, U3.39 (GPIO27_ADC1)
/GPIO28_ADC2: J4.3, U3.40 (GPIO28_ADC2)
/GPIO29_ADC3: J4.1, U3.41 (GPIO29_ADC3)
/QSPI_SCLK: U2.6 (CLK), U3.52 (QSPI_SCLK)
/QSPI_SD0: U2.5 (DI(IO0)), U3.53 (QSPI_SD0)
/QSPI_SD1: U2.2 (DO(IO1)), U3.55 (QSPI_SD1)
/QSPI_SD2: U2.3 (IO2), U3.54 (QSPI_SD2)
/QSPI_SD3: U2.7 (IO3), U3.51 (QSPI_SD3)
/QSPI_SS: R1.1, R2.2, U2.1 (~CS), U3.56 (QSPI_SS)
/RUN: J4.29, U3.26 (RUN)
/SCK: R7.1, U3.28 (GPIO17), U4.4 (SCK)
/SDI: R6.1, U3.27 (GPIO16), U4.3 (SDI)
/SWCLK: J4.33, U3.24 (SWCLK)
/SWD: J4.31, U3.25 (SWD)
/USB_D+: J1.3 (D+), R3.1
/USB_D-: J1.2 (D-), R4.1
/XIN: C2.1, U3.20 (XIN), Y1.1
/XOUT: R5.1, U3.21 (XOUT)
/~USB_BOOT: J2.1, R1.2
GND: C1.2, C2.2, C3.2, C4.2, C5.2, C6.2, C7.2, C8.2, C9.2, C10.2, C11.2, C12.2, C13.2, C14.2, C15.2, C16.2, C17.2, C19.2, J1.5 (GND), J1.6 (Shield), J2.2, J3.1, J3.3, J3.5, J3.7, J3.9, J3.11, J3.13, J3.15, J3.17, J3.19, J3.21, J3.23, J3.25, J3.27, J3.29, J3.31, J3.33, J3.35, J3.36, J4.2, J4.4, J4.6, J4.8, J4.10, J4.12, J4.14, J4.16, J4.18, J4.20, J4.22, J4.24, J4.26, J4.28, J4.30, J4.32, J4.34, J4.35, J4.36, U1.1 (GND), U2.4 (GND), U3.19 (TESTEN), U3.57 (GND), U4.1 (GND), U4.5 (SDO), U4.7 (GND)
unnamed: C3.1, R5.2, Y1.2
unnamed: R4.2, U3.46 (USB_DM)
unnamed: R3.2, U3.47 (USB_DP)
unnamed: C18.2, R6.2, R7.2, U4.2 (CSB)
VBUS: C1.1, J1.1 (VBUS), U1.3 (VI)

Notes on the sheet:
Make sure C8 is close to pin 45 of RP2040
Make sure C10 is close to pin 44 of RP2040
Power
Crystal
Flash
IOs
Make sure R3 and R4 are close to RP2040

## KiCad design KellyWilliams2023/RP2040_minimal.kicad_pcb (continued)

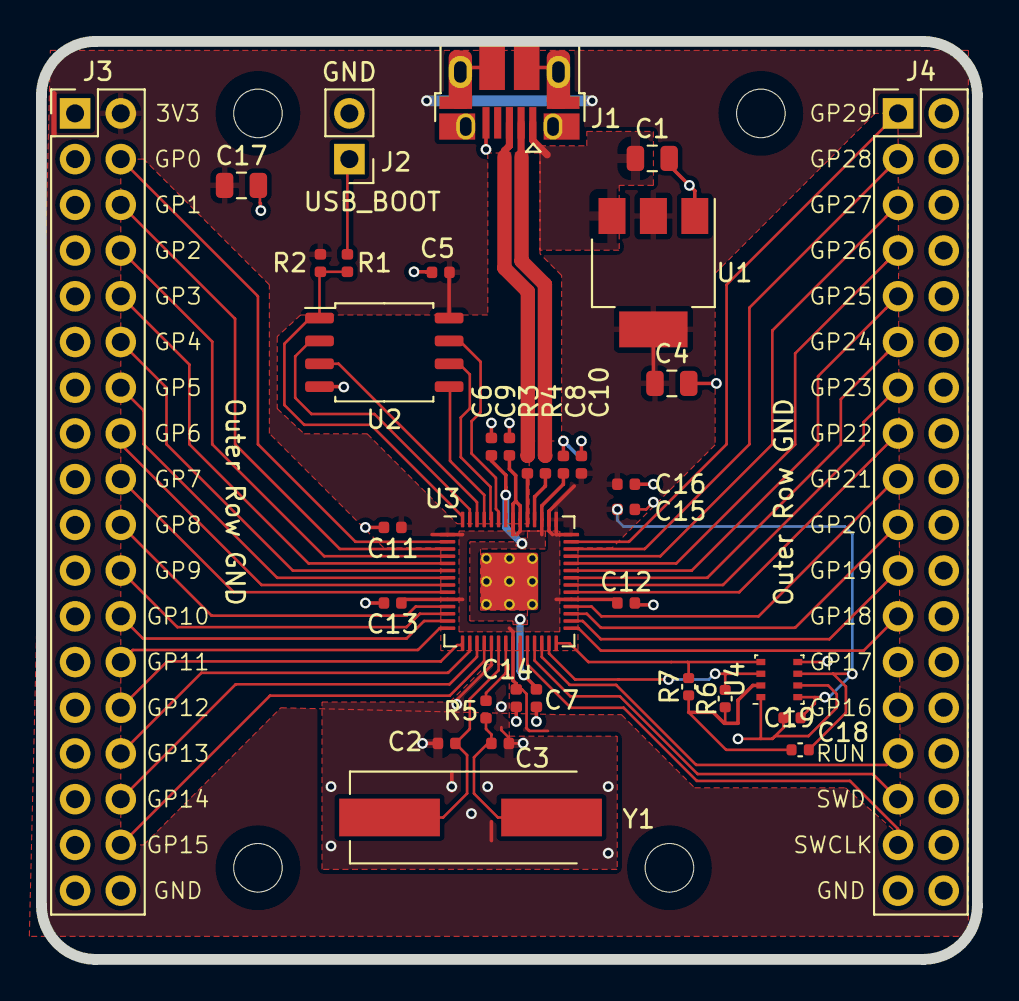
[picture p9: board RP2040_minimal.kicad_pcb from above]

Board: 2 copper layers, 52.0 x 51.0 mm, 39 parts (0 on the bottom side), 52 nets.

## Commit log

2024-05-24 Kelly's Eval
    [RP2040_minimal-B_Cu.gbr, RP2040_minimal-B_Mask.gbr, RP2040_minimal-B_Paste.gbr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]
2024-05-29 InitialCommit
    RP2040 Evaluation Board
    [BOM-BroncoSpaceRP2040.csv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]
2024-05-29 Updated stuff
    [BOM-BroncoSpaceRP2040.csv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]
2024-06-05 Noob
    first time using github
    [pcb_design_1-CuBottom.gbr, pcb_design_1-CuTop.gbr, pcb_design_1-EdgeCuts.gbr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]
2024-06-05 Updated Production Files
    [pcb_design_1-CuBottom.gbr, pcb_design_1-CuTop.gbr, pcb_design_1-EdgeCuts.gbr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]
